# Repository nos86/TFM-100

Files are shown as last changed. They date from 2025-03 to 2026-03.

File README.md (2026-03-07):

# TFM-100 — Thermal Flow Meter

> **TFM-100** is an open-source embedded system for monitoring thermal energy in hydronic circuits. It measures supply and return water temperatures together with volumetric flow rate, calculates instantaneous power and cumulative energy, and publishes all data in real time over a CAN bus (J1939) and a USB serial interface.

---

## Table of Contents

1. [Project Overview](#1-project-overview)
2. [Hardware](#2-hardware)
3. [Firmware](#3-firmware)
4. [Interface Software — Web UI](#4-interface-software--web-ui)
5. [Communication Protocols](#5-communication-protocols)
6. [Repository Structure](#6-repository-structure)
7. [Getting Started](#7-getting-started)
8. [Hardware Design Files](#8-hardware-design-files)

---

## 1. Project Overview

The TFM-100 is designed for installation in heating/cooling systems. It continuously reads two PT100 RTD temperature probes (supply and return lines) and a pulse-output flow sensor. From these three measurements it computes:

| Measurement | Description |
|---|---|
| Supply temperature | Raw and low-pass-filtered temperature of the supply line |
| Return temperature | Raw and low-pass-filtered temperature of the return line |
| Flow rate | Volumetric flow in litres per hour |
| Thermal power | Instantaneous power in Watts (ΔT × flow × specific heat) |
| Energy total | Cumulative energy in Wh, persisted to EEPROM |
| Energy (24 h) | Rolling 24-hour energy counter, persisted to EEPROM |

All measurements are broadcast on a J1939 CAN bus and are also streamed over USB serial for direct PC access. A browser-based Web UI connects via the **WebSerial API** to display live telemetry, diagnostic trouble codes (DTCs), and a scrolling log—no driver installation required.

---

## 2. Hardware

### 2.1 Microcontroller

| Parameter | Value |
|---|---|
| MCU | **ATmega32U4** |
| Clock | 8 MHz external crystal |
| Supply | 5 V system supply and I/O logic (via USB or external 5 V) |
| Brown-out detection | 2.6 V (efuse `0xCB`) |
| Bootloader | Caterina (CDC ACM, `avr109` protocol) |
| Flash | 28 672 bytes usable |

The ATmega32U4 provides native USB (CDC-ACM serial) without an external USB-to-UART bridge, which means it enumerates directly as a serial port on any OS.

> **Firmware note:** The PlatformIO/Arduino firmware is built using the `ARDUINO_AVR_PROMICRO8` (8 MHz Pro Micro) board definition to match the ATmega32U4 clock and bootloader configuration. The TFM-100 PCB operates at **5 V** — all GPIO logic levels are 5 V. It is **not** a 3.3 V Pro Micro, so connect only 5 V–tolerant peripherals or use appropriate level shifting.

### 2.2 Temperature Sensing — PT100 RTDs

Two **PT100** resistance temperature detectors are read by two independent **MAX31865** SPI RTD-to-digital converter ICs. Each MAX31865 performs the resistance-to-temperature conversion on-chip and communicates over SPI.

| Signal | Arduino Pin | MCU Pin |
|---|---|---|
| Supply PT100 CS | D2 (SDA) | PD1 |
| Return PT100 CS | D3 (SCL) | PD0 |
| SPI SCK | SCK | PB1 |
| SPI MOSI | MOSI | PB2 |
| SPI MISO | MISO | PB3 |

A software **low-pass filter** (RC ≈ 5 s, sampled at 100 ms) is applied to each reading to suppress noise before the value is used for energy calculations.

### 2.3 Flow Sensing

A pulse-output flow sensor is connected to the hardware interrupt pin. The firmware counts pulses in an ISR with debouncing and converts ticks to litres per hour using a configurable factor (default: **4 ticks/litre**). A timeout detects sensor removal or zero flow.

| Signal | Arduino Pin | MCU Pin |
|---|---|---|
| Flow pulse | D0 (RX) | PD2 |

### 2.4 CAN Bus — MCP2515

A **MCP2515** SPI-to-CAN controller provides a J1939-compatible CAN 2.0B interface (29-bit extended IDs) at 250 kbit/s.

| Signal | Arduino Pin | MCU Pin |
|---|---|---|
| MCP CS | D4 | PD4 |
| MCP INT | D7 | PE6 |
| SPI (shared with PT100) | SCK / MOSI / MISO | PB1–PB3 |

### 2.5 Node ID Configuration — DIP Switch

Four DIP switch bits select the lower nibble of the J1939 node ID at power-on. The base address is `0x10`, giving a configurable range of `0x10`–`0x1F`.

| Bit | Arduino Pin |
|---|---|
| B0 | D6 |
| B1 | D8 |
| B2 | D9 |
| B3 | D10 |

### 2.6 Status LEDs

| LED | Arduino Pin | Meaning |
|---|---|---|
| Red (RX LED) | `LED_BUILTIN_RX` | Error / fault severity indication (pattern-based: flash counts, blink, solid) |
| Green (TX LED) | `LED_BUILTIN_TX` | Node state indication (pattern-based: RUN / STOP / SLEEP / SETUP / CLI) |

The firmware drives both LEDs with defined patterns rather than fixed on/off states:

| LED | State / Condition | Pattern |
|---|---|---|
| **Green** | CLI client connected | 2.5 Hz blink |
| **Green** | RUN | Solid ON |
| **Green** | SLEEP | Single flash |
| **Green** | SETUP | Inverted flicker (10 Hz) |
| **Green** | STOP | Off |
| **Red** | No fault | Off |
| **Red** | Severity 1 | Single flash |
| **Red** | Severity 2 | Double flash |
| **Red** | Severity 3 | Triple flash |
| **Red** | Severity 4 (critical) | Solid ON |
| **Red** | Severity 5 (warning) | 2.5 Hz blink |
| **Red** | Severity > 5 | 10 Hz flicker |

---

## 3. Firmware

The firmware is written in C++ for the Arduino / PlatformIO ecosystem and targets the ATmega32U4. It is structured as a set of loosely coupled modules that all run cooperatively under a lightweight task scheduler.

### 3.1 Architecture Overview

```
┌─────────────────────────────────────────────────────────────┐
│                        main loop                            │
│  scheduler::run() dispatches tasks at configured intervals  │
└───────────┬──────────┬──────────┬─────────────┬────────────┘
            │          │          │             │
     ┌──────▼──┐  ┌────▼────┐  ┌──▼───────┐  ┌──▼────────┐
     │  PT100  │  │  Flow   │  │ J1939Mgr │  │  Serial   │
     │ sensor  │  │ sensor  │  │  (CAN)   │  │  CLI/Log  │
     └──────┬──┘  └────┬────┘  └──────────┘  └──────────┘
            │          │
     ┌──────▼──────────▼──────┐
     │  power.cpp / energy.cpp│  (calculations + EEPROM persistence)
     └────────────────────────┘
```

### 3.2 Key Modules

| Module | Source | Description |
|---|---|---|
| **Scheduler** | `lib/scheduler/` | Cooperative task scheduler; each task specifies its interval in milliseconds |
| **PT100 driver** | `lib/PT100/` | Non-blocking MAX31865 driver with built-in low-pass filter |
| **Flow sensor** | `lib/flow/` | ISR-driven pulse counter with debounce and zero-flow timeout |
| **J1939 Manager** | `lib/J1939/` | Complete J1939 stack: message registry, single-frame TX, BAM Transport Protocol |
| **J1939 DM1** | `lib/J1939/J1939_DM.cpp` | Diagnostics Module 1 — broadcasts active DTCs on the CAN bus |
| **Serial Protocol** | `lib/SerialProtocol/` | ASCII line-oriented CLI (see §5.2) |
| **Diagnostics** | `lib/diagnostics/` | DTC storage, debouncing, SPN/FMI encoding |
| **Power** | `src/power.cpp` | Computes instantaneous thermal power from ΔT and flow |
| **Energy** | `src/energy.cpp` | Integrates power over time; persists totals to EEPROM once per minute |
| **CAN messages** | `src/can_messages.cpp` | Concrete J1939 message objects (Heartbeat, Temperature, Power/Energy) |
| **CLI** | `src/cli.cpp` | Handles host commands (calibration, memory read/write, reboot) |
| **LEDs** | `src/LEDs.cpp` | Maps system state to LED patterns |
| **DIP switch** | `src/dip_switch.cpp` | Reads node-ID DIP switch at startup |

### 3.3 EEPROM Layout

| Region | Offset | Size | Contents |
|---|---|---|---|
| Power | `0x1A–0x1F` | 6 B | Magic word + max observed power |
| Energy | `0x20–0x29` | 10 B | Magic word + cumulative energy + 24 h energy |
| Diagnostics | `0x40+` | variable | DTC ring buffer |

Compile-time `static_assert` guards prevent accidental region overlaps.

### 3.4 CAN Message Summary

All CAN messages use **little-endian (LSB-first)** byte order for multi-byte fields.

| PGN | Period | Payload |
|---|---|---|
| `0xFF10` Heartbeat | 1 s | MODEL (byte 0), firmware version (byte 1), variant & node state (byte 2: high nibble = variant, low nibble = node state), reserved (byte 3), uptime counter (bytes 4–7, little-endian) |
| `0xFF11` Raw Temperature | 1 s | Supply & return raw temperatures (×100, 0.01 °C/LSB, little-endian) |
| `0xFF12` Filtered Temp + Flow | 1 s | Filtered temperatures (×100, 0.01 °C/LSB, little-endian) + flow rate (L/h) |
| `0xFF13` Power & Energy | 1 s | 24 h energy (bytes 0–1, 0.01 kWh/LSB) + energy total (bytes 2–4, 24-bit, 1 kWh/LSB) + power (bytes 5–6, 0.1 kW/LSB) + reserved (byte 7) |
| `0xFECA` DM1 | configured interval (while DTCs active; one final frame on clear) | Active diagnostic trouble codes (SPN + FMI) |

### 3.5 Build & Flash

Requirements: [PlatformIO](https://platformio.org/) (VS Code extension or CLI).

```bash
# Build firmware
cd firmware
pio run

# Flash over USB (Caterina bootloader — press reset twice to enter bootloader)
pio run --target upload

# Open serial monitor
pio device monitor --baud 115200
```

The custom board definition (`firmware/boards/TFM_100.json`, with variants in `firmware/boards/variants/TFM_100/`) sets `8 MHz`, `5V`, and the correct fuse bytes.

---

## 4. Interface Software — Web UI

The **TFM-100 Web UI** is a single-page application built with **Vue 3** and **Vuetify 3**. It runs entirely in the browser and communicates with the device using the [**WebSerial API**](https://developer.mozilla.org/en-US/docs/Web/API/Web_Serial_API) (no driver, no backend required).

> **Browser support**: Chromium-based browsers (Chrome 89+, Edge 89+). Firefox and Safari do not yet support WebSerial.

### 4.1 Features

| Feature | Description |
|---|---|
| **Live telemetry** | Real-time display of all `P;key;value` parameters (temperatures, flow, power, energy) |
| **Diagnostics panel** | Shows active DTCs with SPN-FMI codes and human-readable descriptions |
| **Log viewer** | Scrolling log output of device messages |
| **Serial connection** | Quick connect/disconnect to a selected serial port via the WebSerial API |
| **Browser-only UI** | Runs entirely in the browser; no drivers or backend services required |

### 4.2 Running the Web UI

Requirements: [Node.js](https://nodejs.org/) 18+.

```bash
cd webui
npm install
npm run dev        # Development server with hot-reload
npm run build      # Production build → dist/
```

### 4.3 UI Architecture

```
webui/src/
├── App.vue                      # Root component, serial lifecycle
├── components/
│   ├── TelemetryCard.vue       # Temperature / flow / power / energy display
│   ├── DiagnosticsCard.vue     # DTC list
│   ├── LogFooter.vue           # Scrolling log
│   └── SerialCard.vue          # Manual command input
└── plugins/webserial/
    ├── service.ts              # WebSerial API wrapper
    ├── composable.ts           # Vue reactive composable
    └── adapter.ts              # Serial protocol framing & parsing
```

---

## 5. Communication Protocols

### 5.1 J1939 CAN Bus

TFM-100 uses the **SAE J1939** protocol over a 250 kbit/s CAN 2.0B network with 29-bit extended identifiers.

The `J1939Manager` library provides:

- **Message registration** — up to 10 message types with configurable TX periods.
- **Single-frame TX** — payloads ≤ 8 bytes sent directly.
- **BAM Transport Protocol** — larger payloads fragmented and reassembled per SAE J1939-21.
- **DM1 diagnostics** — active DTC broadcast whenever fault state changes.

### 5.2 USB Serial (ASCII CLI)

A line-oriented ASCII protocol is used for configuration, diagnostics, and log streaming over USB CDC-ACM. All frames are semicolon-delimited and terminated with `\r\n`.

#### Host → Device (Commands)

| Command | Format | Description |
|---|---|---|
| Erase diagnostics | `E\r\n` | Clears the DTC ring buffer in EEPROM |
| Set calibration | `C;<id>;<value>\r\n` | Write a calibration coefficient |
| Read memory | `R;<chip>;<addr_hex>;<len_dec>\r\n` | Dump raw memory (`len` is a decimal byte count) |
| Write memory | `W;<chip>;<addr_hex>;<data_hex>\r\n` | Write raw bytes |
| Reboot | `B\r\n` | Software reset |

#### Device → Host (Uplink)

| Frame | Format | Description |
|---|---|---|
| Telemetry | `P;<key>;<value>\r\n` | Named parameter (e.g. `P;ST;43.2`) |
| Log | `L;<level>;<message>\r\n` | Level: `E`/`W`/`I`/`D` |
| DTC count | `D;<count>\r\n` | Number of stored DTCs |
| DTC entry | `D;<idx>;<desc>;<SPN>-<FMI>;<status>;<oc>\r\n` | Individual trouble code |
| Memory dump | `V;<chip>;<addr_hex>;<len_hex>;<hex_data>\r\n` | Response to `R` command (`len_hex` is exactly 2 hex digits; `addr_hex` is up to 8 hex digits) |
| Calibration | `C;<id>;<type>;<value>\r\n` | Current calibration value |

A full protocol specification is available in [PROTOCOL.md](PROTOCOL.md).

---

## 6. Repository Structure

```
TFM-100/
├── README.md                    # This file
├── PROTOCOL.md                  # Full serial CLI protocol specification
├── firmware/                    # ATmega32U4 firmware (PlatformIO / C++)
│   ├── src/                     # Application source files
│   ├── include/                 # Project-wide headers and config
│   ├── lib/                     # Reusable libraries
│   │   ├── J1939/               # J1939 CAN stack
│   │   ├── SerialProtocol/      # ASCII serial protocol
│   │   ├── PT100/               # MAX31865 RTD driver
│   │   ├── flow/                # Flow sensor driver
│   │   ├── scheduler/           # Cooperative task scheduler
│   │   └── diagnostics/         # DTC management
│   ├── boards/TFM_100.json      # Custom PlatformIO board definition
│   ├── boards/variants/TFM_100/ # Board-specific pin/variant files
│   └── platformio.ini           # Build configuration
├── webui/                       # Browser-based monitoring UI (Vue 3)
│   ├── src/
│   │   ├── components/          # Vue components
│   │   └── plugins/webserial/   # WebSerial API integration
│   └── package.json
├── hardware/                    # PCB design and manufacturing files
│   ├── schematics.pdf           # Circuit schematic
│   ├── board.png                # PCB layout preview
│   ├── ThermalFlowMeter-BoM.xlsx          # Bill of Materials
│   ├── ThermalFlowMeter_PickAndPlace.xlsx # Pick & place data
│   ├── ThermalFlowMeter-gerber.zip        # Gerber files (ready for fab)
│   └── easyeda_project.epro               # EasyEDA schematic project
└── bootloader/                  # Bootloader flashing guide & hex file
    └── README.md                # avrdude flashing instructions
```

---

## 7. Getting Started

### Prerequisites

| Tool | Purpose |
|---|---|
| [PlatformIO](https://platformio.org/) | Firmware build & upload |
| [Node.js 18+](https://nodejs.org/) | Web UI development |
| USBasp programmer | Initial bootloader programming (if blank chip) |
| Chromium-based browser | Web UI runtime |

### Step 1 — Flash the Bootloader (first time only)

If your ATmega32U4 is blank, follow the instructions in [`bootloader/README.md`](bootloader/README.md) to flash the Caterina USB bootloader using a USBasp programmer.

### Step 2 — Build and Upload Firmware

```bash
cd firmware
pio run --target upload   # Connect USB; double-tap reset to enter bootloader
```

### Step 3 — Run the Web UI

```bash
cd webui
npm install
npm run dev
```

Open `http://localhost:3000` in Chrome or Edge, click **Connect**, and select the TFM-100 serial port.

---

## 8. Hardware Design Files

All hardware design files are located in the [`hardware/`](hardware/) directory.

| File | Description |
|---|---|
| `schematics.pdf` | Full circuit schematic |
| `board.png` | PCB layout preview image |
| `ThermalFlowMeter-BoM.xlsx` | Bill of Materials |
| `ThermalFlowMeter_PickAndPlace.xlsx` | SMT pick & place data |
| `ThermalFlowMeter-gerber.zip` | Gerber + drill files for PCB fabrication |
| `easyeda_project.epro` | Editable EasyEDA schematic project |

---

*For questions, bug reports, or contributions, please open an issue or pull request on this repository.*

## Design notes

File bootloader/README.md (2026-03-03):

# Flashing the Bootloader on ATmega32U4 Using avrdude

This guide explains how to flash the bootloader onto an ATmega32U4 microcontroller
using a USBasp programmer and the `avrdude` command. It covers the necessary pin
connections and explains the meaning of fuse settings.

## Prerequisites

*   **ATmega32U4 microcontroller**: The target chip for the bootloader.
*   **USBasp programmer**: A low-cost USB programmer for Atmel AVR microcontrollers.
*   **avrdude**: The tool used to interface with the ATmega32U4 via the USBasp.
*   **Caterina Bootloader Hex File**: The bootloader file (`Caterina-promicro8.hex`)
    for the ATmega32U4.

## Hardware Setup

### Step 1: Connect the USBasp to the ATmega32U4

The USBasp exposes a standard 10-pin AVR ISP header. The pin numbering (odd pins
on the left column, even pins on the right column, pin 1 indicated by the triangle
or notch on the connector) is:

```
10-pin AVR ISP header (front view)
        ┌───────┬
 MOSI ← │  1  2 │ → VCC
   NC ← │  3  4 │ → GND
  RST ← │  5  6 │ → GND
  SCK ← │  7  8 │ → GND
 MISO ← │  9 10 │ → GND
        └───────┘
```

Connect the relevant signals to the ATmega32U4 as follows:

| 10-pin ISP Pin | Signal | ATmega32U4 Pin |
| --- | --- | --- |
| 1 | MOSI | MOSI |
| 2 | VCC | **CONNECTED ONLY IF 3.3V** |
| 4 / 6 / 8 / 10 | GND | GND |
| 5 | RST | RESET |
| 7 | SCK | SCK |
| 9 | MISO | MISO |

> **Note**: This board uses a 3.3 V power supply. Use VCC from USBasp
> only if it is able to provide 3.3V and **NOT** 5V, otherwise power the
> target board separately via USB.

#### Adapter for 6-pin ICSP Connectors

To simplify the connection with standard 6-pin ICSP header, you can use a 10-to-6 
pin ISP adapter to connect the USBasp directly without individual wires:

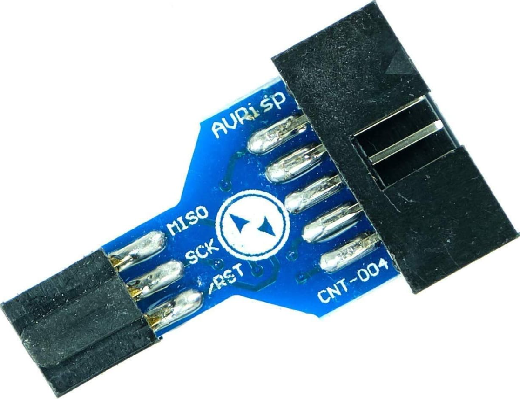
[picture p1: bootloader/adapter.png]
10-to-6 pin ISP adapter


These adapters convert the USBasp 10-pin IDC connector to the 6-pin ICSP layout and
are widely available online.

### Step 2: Verify the Connections

Make sure the connections are correct as outlined in the table above before
proceeding to the next steps.

## Flashing the Bootloader

Once the hardware is set up, flash the bootloader on the ATmega32U4 using `avrdude`.

### Step 3: Program the Fuses

Because the crystal oscillator fuses may be incorrectly configured, the ISP clock
must be reduced to a very low speed (`-B400`) for the initial fuse programming step.

Run the following command from the terminal:

```bash
avrdude -cusbasp -pm32u4 -B400 -U lfuse:w:0xFF:m -U hfuse:w:0xD8:m -U efuse:w:0xCB:m
```

**Explanation of flags:**

*   `-cusbasp`: Selects the USBasp as the programmer.
*   `-pm32u4`: Targets the ATmega32U4 microcontroller.
*   `-B400`: Sets the ISP bit-clock period to 400 µs (very slow) to communicate
    reliably when the crystal is not yet configured correctly.
*   `-U lfuse:w:0xFF:m`: Sets the low fuse to `0xFF` (external crystal, no
    prescaler).
*   `-U hfuse:w:0xD8:m`: Sets the high fuse to `0xD8` (`BOOTRST` programmed so
    the chip resets into the bootloader; `BOOTSZ=00` selects the 4096-byte
    bootloader section).
*   `-U efuse:w:0xCB:m`: Sets the extended fuse to `0xCB` (Brown-Out Detection
    threshold at 2.4 V; Hardware Boot Enable pin disabled).

### Step 4: Flash the Bootloader

After the fuses are correctly set the chip can be programmed at full ISP speed.

Run the following command from the terminal:

```bash
avrdude -cusbasp -pm32u4 -e -U flash:w:Caterina-promicro8.hex
```

**Explanation of flags:**

*   `-cusbasp`: Selects the USBasp as the programmer.
*   `-pm32u4`: Targets the ATmega32U4 microcontroller.
*   `-e`: Erases the flash memory of the ATmega32U4 before programming.
*   `-U flash:w:Caterina-promicro8.hex`: Writes the Caterina bootloader to flash.

### Step 5: Wait for the Process to Complete

`avrdude` will write the bootloader to the ATmega32U4. Wait for the process to
finish. You should see a message indicating successful programming.

## Fuse Explanation

Fuses are special bits stored in the ATmega32U4 that control the hardware
configuration of the microcontroller, such as the clock source, bootloader settings,
and memory protection. This guide uses three fuse bytes:

*   **LFUSE (Low Fuse) = `0xFF`**: Selects the external crystal oscillator as the
    clock source with no clock division (prescaler = 1). The chip runs at the full
    8 MHz frequency of the external crystal.

*   **HFUSE (High Fuse) = `0xD8`** (`0xD8` = `0b11011000`):
    *   `BOOTRST` = 0 (programmed, active-low): the MCU jumps to the bootloader
        section on every reset, enabling USB programming.
    *   `BOOTSZ[1:0]` = `00` (both bits programmed): selects the maximum 2048-word
        (4096-byte) bootloader section.
    *   `SPIEN` = 0 (programmed): SPI programming interface enabled.

*   **EFUSE (Extended Fuse) = `0xCB`** (`0xCB` = `0b11001011`):
    *   `BODLEVEL[2:0]` = `011`: sets the Brown-Out Detection threshold to 2.6 V,
        preventing flash corruption if the supply voltage drops too low.
    *   `HWBE` = 1 (unprogrammed): the Hardware Boot Enable pin (HWB) is disabled;
        the bootloader is always entered on reset (see `BOOTRST` above).

## Troubleshooting

*   **Verification error**: Re-run the `avrdude` command with the `-v` flag for
    verbose output to help diagnose the problem.
*   **USBasp not detected**: Ensure the USBasp is properly connected via USB and
    that its drivers are installed. On Linux you may need to add a udev rule or run
    `avrdude` with `sudo`.

---

This guide provides step-by-step instructions to program an ATmega32U4 with the
**Caterina bootloader** using a USBasp programmer and explains the fuse settings.
Follow the steps carefully to ensure successful bootloader flashing.

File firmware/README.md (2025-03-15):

# ATmega32U4-Arduino Pin Mapping

A diagram showing the correspondence between the pins on an Arduino board and those of the ATmega32U4 microcontroller.

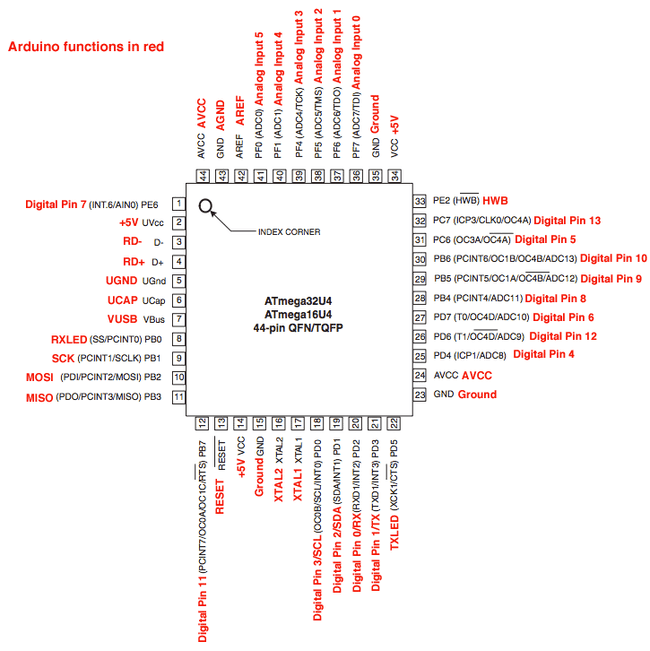
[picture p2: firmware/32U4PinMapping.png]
32U4 Pin Mapping


**Last revision:** 08/02/2024

## ATmega32U4 Pin Mapping

### Arduino Leonardo Pin Mapping Table

| Pin Number | Pin Name | Mapped Pin Name |
|---|---|---|
| 1 | PE6 (INT.6/AIN0) | Digital pin 7 |
| 2 | UVcc | +5V |
| 3 | D- | RD- |
| 4 | D+ | RD+ |
| 5 | UGnd | UGND |
| 6 | UCap | UCAP |
| 7 | VUSB | VBus |
| 8 | (SS/PCINT0) PB0 | RXLED |
| 9 | (PCINT1/SCLK) PB1 | SCK |
| 10 | (PDI/PCINT2/MOSI) PB2 | MOSI |
| 11 | (PDO/PCINT3/MISO) PB3 | MISO |
| 12 | (PCINT7/OC0A/OC1C/#RTS) PB7 | Digital pin 11 (PWM) |
| 13 | RESET | RESET |
| 14 | Vcc | +5V |
| 15 | GND | GND |
| 16 | XTAL2 | XTAL2 |
| 17 | XTAL1 | XTAL1 |
| 18 | (OC0B/SCL/INT0) PD0 | Digital pin 3 (SCL)(PWM)  |
| 19 | (SDA/INT1) PD1 | Digital pin 2 (SDA) |
| 20 | (RX D1/AIN1/INT2) PD2 | Digital pin 0 (RX) |
| 21 | (TXD1/INT3) PD3 | Digital pin 1 (TX) |
| 22 | (XCK1/#CTS) PD5 | TXLED |
| 23 | GND1 | GND |
| 24 | AVCC | AVCC |
| 25 | (ICP1/ADC8) PD4 | Digital pin 4 |
| 26 | (T1/#OC4D/ADC9) PD6 | Digital pin 12 |
| 27 | (T0/OC4D/ADC10) PD7 | Digital Pin 6 (PWM) |
| 28 | (ADC11/PCINT4) PB4 | Digital pin 8 |
| 29 | (PCINT5/OC1A/#OC4B/ADC12) PB5 | Digital Pin 9 (PWM) |
| 30 | (PCINT6/OC1B/OC4B/ADC13) PB6  | Digital Pin 10 (PWM) |
| 31 | (OC3A/#0C4A) PC6 | Digital Pin 5 (PWM) |
| 32 | (ICP3/CLK0/)0C4A) PC7 | Digital Pin 13 (PWM) |
| 33 | (#HWB) PE2 | HWB |
| 34 | Vcc1 | +5V |
| 35 | GND2 | GND |
| 36 | (ADC7/TDI) PF7 | Analog In 0 |
| 37 | (ADC6/TDO) PF6 | Analog In 1 |
| 38 | (ADC5/TMS) PF5 | Analog In 2 |
| 39 | (ADC4/TCK) PF4 | Analog In 3 |
| 40 | (ADC1) PF1 | Analog In 4 |
| 41 | (ADC0) PF0 | Analog In 5 |
| 42 | AREF | AEF |
| 43 | GND3 | GND |
| 44 | AVCC1 | AVCC |

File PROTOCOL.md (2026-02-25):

# TFM-100 Serial / CLI Protocol

## Scope

This document describes the simple, line-oriented serial protocol implemented by the firmware's `SerialProtocol` (see `firmware/lib/SerialProtocol/SerialProtocol.*`). It's used for diagnostics, configuration (calibration), and binary memory read/write operations. The protocol is intentionally minimal and human-readable for easy debugging over serial terminals and bridges.

## Framing

- Messages are ASCII, terminated by LF ("\n") and CR ("\r"), even if, it is optional. Each message is a semicolon-separated list of tokens.
- No binary framing, no escaping. Maximum line size is limited by the firmware buffer (~128 bytes).

## Command directions

- Uplink (host -> device): single-letter commands the firmware parses when a line arrives.
- Downlink (device -> host): responses and notifications emitted by the firmware using the same semicolon-separated format.

## Uplink (host -> device) commands

- `E`
  - Erase diagnostics memory. No parameters.
  - Handler: triggers the erase diagnostics callback (set via `set_erase_diagnostics_callback`).
  - Answer: device will respond with:
    - `E;OK\r\n` on success
    - `E;ERR;error_code\r\n` on failure

- `C;id;value`
  - Calibration command: it is used to change calibration in the firmware.
    - `id` is the identifier of the calibration. Only calibration with identifier can be modified.
    - `value` is an arbitrary string payload interpreted by the firmware.
  - Example: `C;1;5.2\r\n`
  - Handler: triggers the calibration callback (set via `set_calibration_callback`).
  - Answer: device will response as:
    - `C;OK\r\n` to indicate success
    - `C;ERR;error_code\r\n` to indicate failure
- `R;chip_id;addrhex;lenhex`
  - Read address on companion chips:
    - `chip_id` is decimal chip id
    - `addrhex` is an address in hex (big-endian, no 0x)
    - `lenhex` is a decimal length.
  - Example: `R;0;1F2A;16\r\n` (read 16 bytes from address 0x1F2A of chip 0)
  - Handler: triggers the read callback (set via `set_read_callback`).
  - Answer: device will respond with:
    - `V;chip;addrhex;lenhex;datahex\r\n` on success
    - `V;ERR;error_code\r\n` on failure

- `W;chip_id;addrhex;datahex`
  - Write address on companion chips:
    - `chip_id` is decimal chip id
    - `addrhex` is an address in hex (big-endian, no 0x)
    - `datahex` is even-length hex-encoded bytes. Max data length limited by firmware (48 bytes).
  - Example: `W;0;1F2A;0A1B2C3D\r\n` (write bytes 0x0A,0x1B,0x2C,0x3D to address 0x1F2A)
  - Handler: triggers the write callback (set via `set_write_callback`).
  - Answer: device will respond with:
    - `W;OK\r\n` on success
    - `W;ERR;error_code\r\n` on failure

- `B`
  - Reboot. No parameters.
  - Handler: triggers the reboot callback (set via `set_reboot_callback`).
  - Answer: device will respond with `B;OK\r\n` and then reboot.

## Downlink (device -> host) messages

- `P;key;value`
  - Parameter report:
    - `key` is a short ASCII key
    - `value` is a decimal or string. Used for telemetry/parameters.
  - Example: `P;ST;43.2\r\n` (parameter "ST" with value 43.2 - Supply Temperature)

- `L;level;message`
  - Log line:
    - `level` is one of `E` (error), `W` (warning), `I` (info), `D` (debug).
  - Example: `L;I;Initialization complete\r\n`

- `D;count`
  - Diagnostics count: it indicates how many diagnostic trouble codes (DTCs) are currently stored in the device.

- `D;index;Description;SPN-FMI;status;OC`
  - Diagnostics entry. Each line provides details about a specific DTC:
    - `index`: zero-based index of the DTC.
    - `Description`: human-readable description of the DTC.
    - `SPN-FMI`: SPN and FMI code in hex format `SPN-FMI` (e.g., `12F4-A`).
    - `status`: indicates the status of DTC (`PENDING`, `ACTIVE`, `HEALING`, `HISTORY`)
    - `OC`: occurrence count (decimal).
  - Example: `D;3\r\n` then several `D;...` lines.

- `V;chip;addrhex;lenhex;datahex`
  - Hex dump of `lenhex` bytes at `addrhex` for `chip`. `lenhex` is exactly two hex digits; `datahex` is twice that many hex chars.
  - It is the response to a read command.
  - Example: `V;0;1F2A;04;0A1B2C3D\r\n`

- `C;id;type;value`
  - Calibration status from device:
    - `id` is the calibration identifier
    - `type` is one of `I`,`F`,`S` (int, float, string)
    - `value` is the current calibration value
  - Example: `C;1;I;0\r\n`

## Error handling and limits

- The parser silently ignores malformed or unknown commands.
- Maximum inbound line length: ~128 bytes. Overflow resets the inbound buffer.
- Max binary write length: 48 bytes (enforced by `DATA_MAX_BYTES`).

## Implementation notes for integrators

- The firmware `DiagComm` wrapper calls `comm.begin()` to install a Serial writer and exposes higher-level helpers (send_param, send_log, send_diag_info, send_v_dump).
- When adding new downlink message types or changing existing formats, update both the firmware serializer and any web UI parsers that consume these lines.
- The wire format is intentionally human-readable. For automation, prefer using the explicit hex fields (for binary blobs) and PGN/field formats for CAN messages.

Examples

- Host requests 16 bytes starting at 0x100 on chip 0:

```text
R;0;0100;16
```

- Device responds with a dump (example):

```text
V;0;0100;10;11223344556677889900AABBCCDDEEFF
```

- Host sets calibration id 2 to value 1.5:

```text
C;2;F;1.5
```

- Device logs an info:

```text
L;I;Flow started
```

Where to find code

- Parser and emitter: `firmware/lib/SerialProtocol/SerialProtocol.h` and `.cpp`.
- Integration wrapper and usage: `firmware/include/diag_comm.h` and `firmware/src/main.cpp`.

License and authorship

- See repository root `README.md` for project authorship. This protocol document is a derivative description of the in-repo implementation.

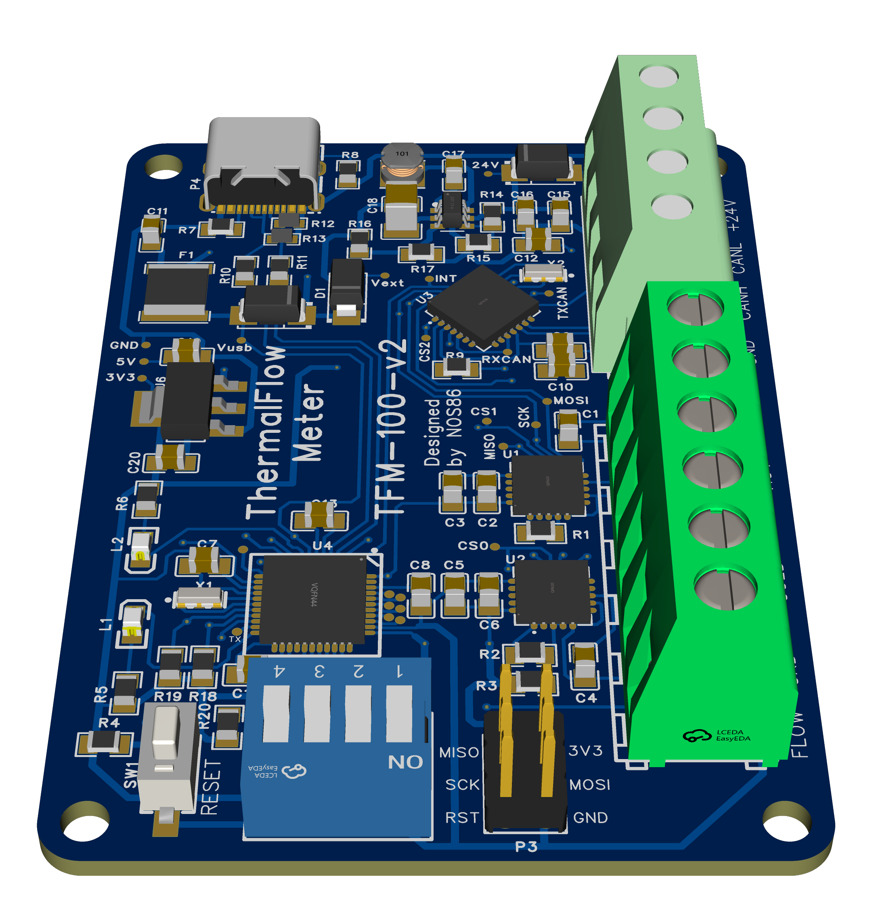
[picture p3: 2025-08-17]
hardware/board.png

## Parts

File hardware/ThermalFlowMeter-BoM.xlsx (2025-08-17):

No. | Quantity | Comment | Designator | Footprint | Value | Manufacturer Part | Manufacturer | Supplier Part | Supplier | JLCPCB Price | Name
1 | 13 | 100nF | C1,C2,C3,C4,C5,C6,C7,C8,C9,C10,C12,C16,C17 | C0805 | 100nF | 0805B104K500NT | FH(风华) | C38141 | LCSC | 0.0006 | 100nF
2 | 2 | 10uF | C11,C19 | C0805 | 10uF | CL21A106KOQNNNE | SAMSUNG(三星) | C1713 | LCSC | 0.0013 | 10uF
3 | 2 | 1uF | C13,C14 | C0805 | 1uF | 0805B105K500NT | FH(风华) | C215803 | LCSC | 0.0014 | 1uF
4 | 1 | 4.7uF | C15 | C0805 | 4.7uF | CL21A475KAQNNNE | SAMSUNG(三星) | C1779 | LCSC | 0.0018 | 4.7uF
5 | 1 | 15uF | C18 | C1210 | 15uF | C3225X7R1C156MT000N | TDK | C694469 | LCSC | 0.0505 | 15uF
6 | 1 | 22uF | C20 | C0805 | 22uF | CL21A226MQQNNNE | SAMSUNG(三星) | C5674 | LCSC | 0.0016 | 22uF
7 | 3 | SS14 | D1,D2,D3 | SMA_L4.3-W2.6-LS5.1-RD |  | SS14 | GOODWORK(固得沃克) | C2986110 | LCSC | 0.0018 | SS14
8 | 1 | MF-SMDF050-2 | F1 | F2018 |  | MF-SMDF050-2 | BOURNS | C210839 | LCSC | 0.0191 | MF-SMDF050-2
9 | 1 | 100uH | H1 | IND-SMD_L3.5-W3.0_SLF0302 | 100uH | CD32YP0302-101M | YJYCOIN(益嘉源) | C492265 | LCSC | 0.0054 | 100uH
10 | 2 | XL-2012SURC | L1,L2 | LED0805-RD_RED |  | XL-2012SURC | XINGLIGHT(成兴光) | C965812 | LCSC | 0.0008 | XL-2012SURC
11 | 1 | MX128-5.0-06P-GN01-Cu-Y-A | P1 | CONN-TH_6P-P5.00_MX128-5.0-06P-GN01-CU-Y-A |  | MX128-5.0-06P-GN01-Cu-Y-A | MAX(迈旭) | C5290371 | LCSC | 0.0502 | MX128-5.0-06P-GN01-Cu-Y-A
12 | 1 | MX128-5.0-04P-GN01-Cu-Y-A | P2 | CONN-TH_4P-MX128-5.0-04P-GN01-CU-Y-A |  | MX128-5.0-04P-GN01-Cu-Y-A | MAX(迈旭) | C5290369 | LCSC | 0.0355 | MX128-5.0-04P-GN01-Cu-Y-A
13 | 1 | 2.54-2*3P针 | P3 | HDR-TH_6P-P2.54-V-M-R2-C3-S2.54-1 |  | 2.54-2*3P针 | BOOMELE(博穆精密) | C65114 | LCSC | 0.0043 | 2.54-2*3P针
14 | 1 | U262-161N-4BVC11 | P4 | USB-3.1-SMD_U262-161N-4BVC11 |  | U262-161N-4BVC11 | XKB Connectivity(中国星坤) | C319148 | LCSC | 0.0309 | U262-161N-4BVC11
15 | 2 | 400Ω | R1,R2 | R0805 | 400Ω | TR0805B400RP0525Z | EVER OHMS(天二科技) | C153298 | LCSC | 0.0043 | 400Ω
16 | 6 | 10kΩ | R3,R4,R9,R18,R19,R20 | R0805 | 10kΩ | 0805W8F1002T5E | UNI-ROYAL(厚声) | C17414 | LCSC | 0.0003 | 10kΩ
17 | 2 | 1kΩ | R5,R6 | R0805 | 1kΩ | 0805W8F1001T5E | UNI-ROYAL(厚声) | C17513 | LCSC | 0.0003 | 1kΩ
18 | 2 | 5.1kΩ | R7,R8 | R0805 | 5.1kΩ | RMC08055.1K5%N | Tyohm(幸亚电阻) | C269736 | LCSC | 0.0006 | 5.1kΩ
19 | 2 | 22Ω | R10,R11 | R0805 | 22Ω | 0805W8F220JT5E | UNI-ROYAL(厚声) | C17561 | LCSC | 0.0003 | 22Ω
20 | 2 | CG0603MLC-05E | R12,R13 | R0603 |  | CG0603MLC-05E | BOURNS | C840634 | LCSC | 0.0278 | CG0603MLC-05E
21 | 1 | 953kΩ | R14 | R0805 | 953kΩ | CR0805F89533G | LIZ(丽智电子) | C101915 | LCSC | 0.0004 | 953kΩ
22 | 1 | 332kΩ | R15 | R0805 | 332kΩ | AC0805FR-07332KL | YAGEO(国巨) | C228750 | LCSC | 0.0006 | 332kΩ
23 | 1 | 95.3kΩ | R16 | R0805 | 95.3kΩ | 0805W8F9532T5E | UNI-ROYAL(厚声) | C17873 | LCSC | 0.0003 | 95.3kΩ
24 | 1 | 22.1kΩ | R17 | R0805 | 22.1kΩ | CR0805-FX-2212ELF | BOURNS | C204311 | LCSC | 0.0016 | 22.1kΩ
25 | 1 | TS-1101-C-W | SW1 | SW-SMD_L6.0-W3.3-LS8.0 |  | TS-1101-C-W | XKB Connectivity(中国星坤) | C318938 | LCSC | 0.0057 | TS-1101-C-W
26 | 1 | SMQS-04R-TP | SW2 | SW-TH_8P-P2.54_SMQS-04R-TP |  | SMQS-04R-TP | SM Switch | C5299505 | LCSC | 0.0341 | SMQS-04R-TP
27 | 2 | MAX31865ATP+T | U1,U2 | QFN-20_L5.0-W5.0-P0.65-BL-EP |  | MAX31865ATP+T | ADI(亚德诺)/MAXIM(美信) | C118474 | LCSC | 0.4788 | MAX31865ATP+T
28 | 1 | MCP25625-E/ML | U3 | QFN-28_L6.0-W6.0-P0.65-BL-EP |  | MCP25625-E/ML | MICROCHIP(美国微芯) | C481365 | LCSC | 0.2769 | MCP25625-E/ML
29 | 1 | ATMEGA32U4-MU | U4 | VQFN-44_L7.0-W7.0-P0.50-BL-EP5.2 |  | ATMEGA32U4-MU | MICROCHIP(美国微芯) | C112161 | LCSC | 0.7507 | ATMEGA32U4-MU
30 | 1 | TPS560430XDBVR | U5 | SOT-23-6_L2.9-W1.6-P0.95-LS2.8-BL |  | TPS560430XDBVR | TI(德州仪器) | C524782 | LCSC | 0.072 | TPS560430XDBVR
31 | 1 | AMS1117-3.3V | U6 | SOT-223-4_L6.5-W3.5-P2.30-LS7.0-TR |  | AMS1117-3.3V | MSKSEMI(美森科) | C5120765 | LCSC | 0.005 | AMS1117-3.3V
32 | 2 | 8MHz | X1,X2 | OSC-SMD_3P-L3.2-W1.3-P1.20-L | 8MHz | CSTNE8M00GH5C000R0 | muRata(村田) | C341525 | LCSC | 0.0323 | 8MHz

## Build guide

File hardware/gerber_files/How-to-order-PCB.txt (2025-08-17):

How to Order PCB

Please refer to:
https://prodocs.easyeda.com/en/pcb/order-order-pcb/index.html

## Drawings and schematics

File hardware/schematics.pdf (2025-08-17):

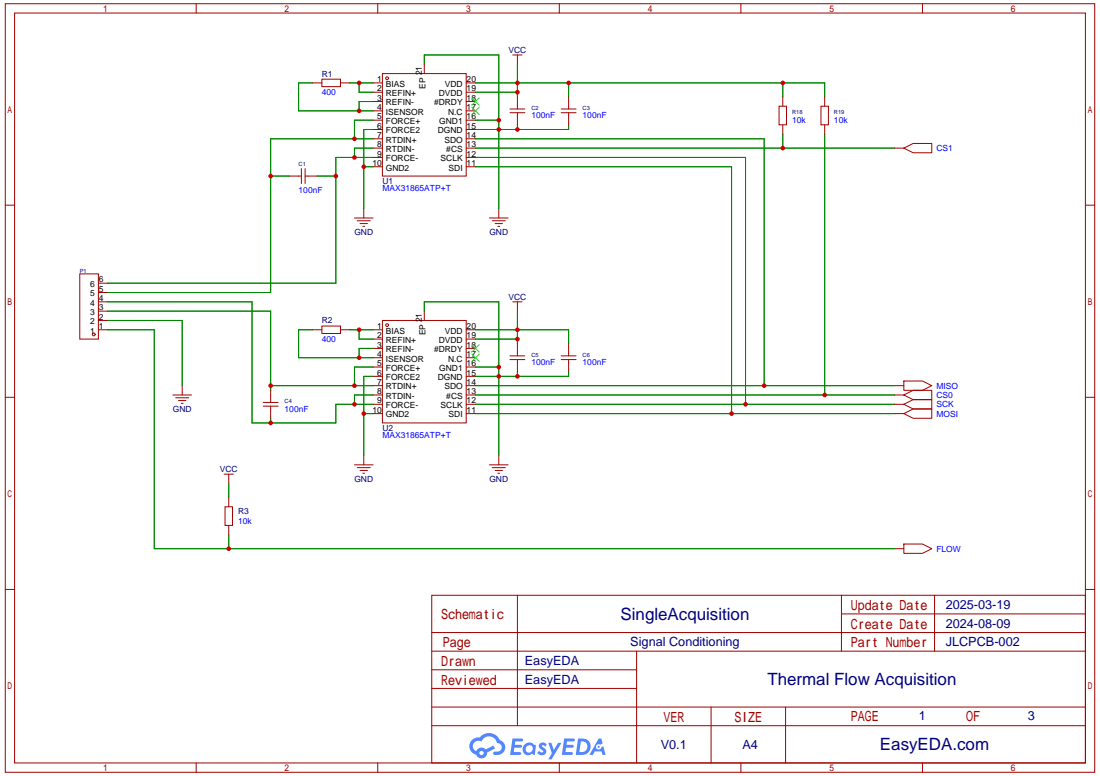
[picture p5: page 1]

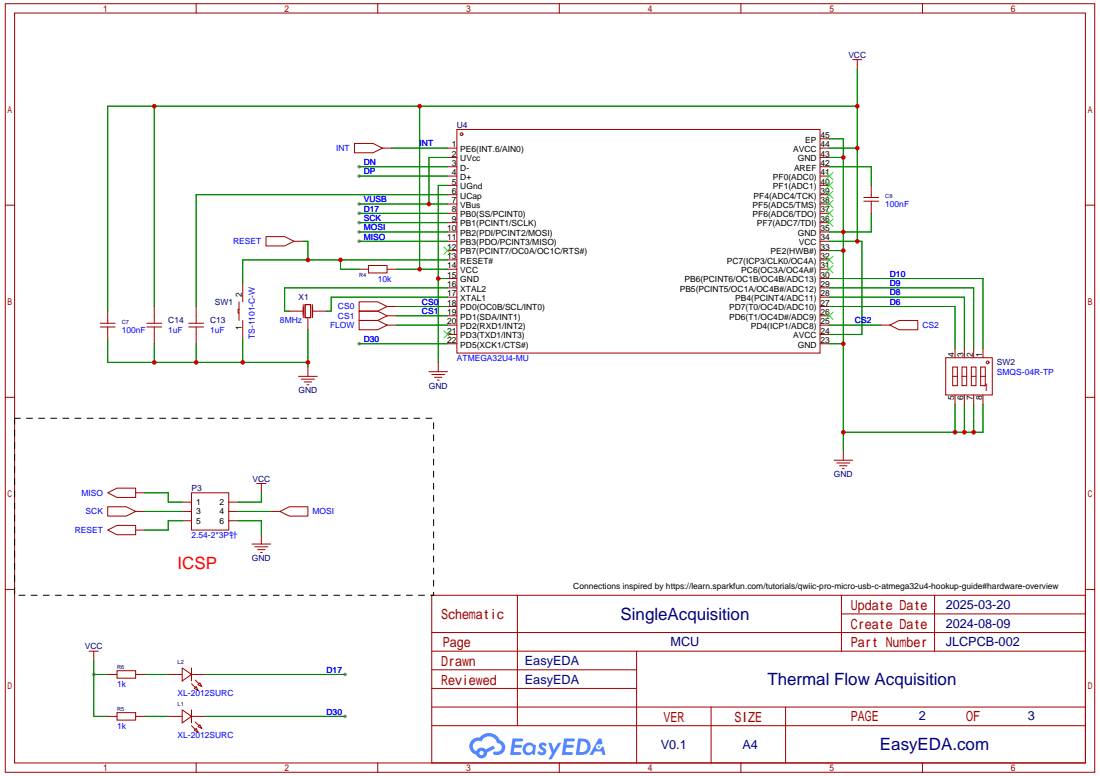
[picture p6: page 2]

Connections inspired by https://learn.sparkfun.com/tutorials/qwiic-pro-micro-usb-c-atmega32u4-hookup-guide#hardware-overview
2024-08-09 SingleAcquisition
MCU

USB Connector | CAN Bus

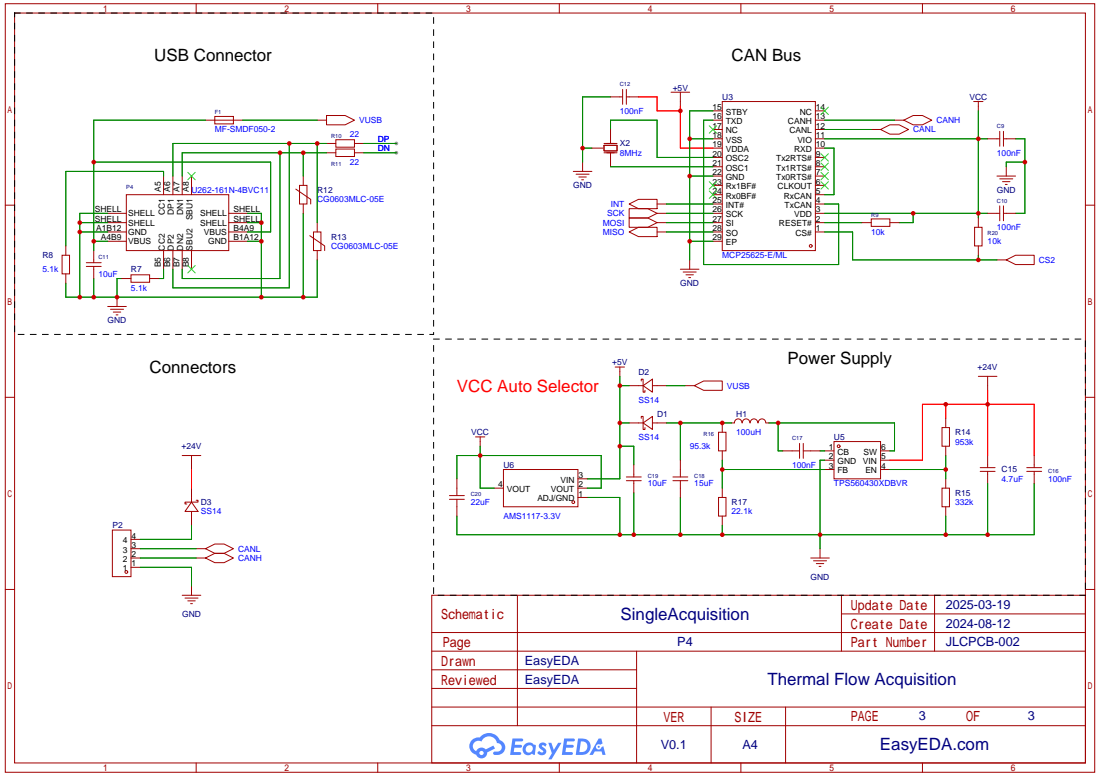
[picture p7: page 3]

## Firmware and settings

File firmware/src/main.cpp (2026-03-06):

/**
 * @file main.cpp
 * @brief Entry point for the TFM-100 firmware: initialize hardware, schedule tasks and run main loop.
 * @author Salvo Musumeci
 * @date 2025-03-09
 *
 * This module configures peripherals (SPI, CAN, sensors), creates the J1939 manager,
 * registers periodic tasks with the cooperative scheduler, and implements the main
 * non-blocking loop that drives sensor state machines and the transport layer.
 */

// The setup function runs once at reset or power-up

// Framework lib
#include <Arduino.h>
#include <SPI.h>
#include "config.h"
#include <avr/wdt.h>
#include <MAX31865_NonBlocking.h>

// MyLib
#include <scheduler.h>
#include <LEDs.h>
#include <PT100.h>
#include <flow.h>
#include <J1939Manager.h>
#include <J1939_DM.h>
#include <diagnostics.h>

// 3rd parties lib
#include <mcp_can.h>

// Include Headers
#include <status.h>
#include <can_messages.h>
#include <McpCanAdapter.h>
#include <dip_switch.h>
#include <dtc.h>
#include <utils.h>
#include <energy.h>
#include <power.h>
#include <diag_comm.h>

/* CLI */

/* Temperature Sensors Variables */
PT100 supply_sensor = PT100(SUPPLY_CS);
PT100 return_sensor = PT100(RETURN_CS);

/* Flow Sensor Variables */
Flow flowObj = Flow(FLOW_TICKS_PER_LITER);
Energy energyObj = Energy();
Power powerObj = Power();

/* Set-up J1939 Transport Layer */
// Allocation of CAN controller and adapter
MCP_CAN CAN0(MCP_CS);           // Set CS to pin 4
McpCanAdapter canAdapter(CAN0); // Adapter per MCP_CAN

// Pass the callbacks struct as the second argument
J1939Callbacks j1939_cbs;

// J1939 Manager instance (created in setup once CAN is initialized)
J1939Manager *j1939 = nullptr; // allocated in setup

/* Node Status */
NodeStatus_t node_status = SETUP;

/* LED Indicators */
LEDs ledIndicators = LEDs(LED_RED, LED_GREEN);

// Scheduler
Scheduler scheduler = Scheduler();

DiagComm diagComm = DiagComm();

/* Node ID */
uint8_t node_id;
uint8_t severity = 0;

bool CANbusOff = false;
bool CANbusWarn = false;
bool HwFailure = true; // Assume HW failure until all init done

// CAN RX interrupt flag
volatile bool canRxPending = false;

/**
 * @brief Interrupt Service Routine for MCP2515 RX interrupt
 * @remarks Called when MCP2515 receives a message. Sets flag for main loop processing.
 */
void canRxInterruptHandler()
{
  canRxPending = true;
}

// serial writer provided below as a free function


/* CAN Messages */
HeartbeatMessage HBMessage = HeartbeatMessage(5000); // 5s interval
CAN_Temperature TempMessage = CAN_Temperature();
CAN_FilteredTemperatureAndFlow TempAndFlowMessage = CAN_FilteredTemperatureAndFlow();
CAN_PowerAndEnergy PowerAndEnergyMessage = CAN_PowerAndEnergy();
J1939_DM1Message DM1 = J1939_DM1Message(1000); // 1s interval

/* Diagnostics */
TFM100_DTC_Dict dtc_dict_instance = TFM100_DTC_Dict();
Diagnostics DSM = Diagnostics(&dtc_dict_instance);

// Forward declaration of J1939Descriptor is available via J1939Manager.h
// Provide a simple error callback to forward J1939 manager errors to CLI
static void j1939_on_error(const J1939Descriptor &desc)
{
  char buf[80];
  // Format PGN in hex with leading 0x using minimal formatter then append message
  mini_hex6(buf, (unsigned long)desc.pgn); // produces 0xNNNNNN\0
  // Append message text after the hex
  char *p = buf + 8;
  const char *msg = " J1939 TX ERROR";
  while (*msg)
    *p++ = *msg++;
  *p = '\0';
  diagComm.send_error(buf);
}

void update_errors();

/**
 * @brief Process received CAN messages
 * @remarks Handles energy reset commands via J1939 Proprietary A message (PGN 0xF183, SA 0x00).
 * Interrupt-driven: only called when canRxPending flag is set by MCP2515 RX interrupt.
 *
 * J1939 Proprietary A Message format:
 * - Priority: 6 (medium)
 * - PGN: 0xF183 (Proprietary A range)
 * - Source Address (SA): 0x00
 * - Combined CAN ID: 0x18F18300
 * - Payload (1-based byte numbering):
 *   - Byte 1: Target node address (0xFF = all nodes, or specific node ID)
 *   - Byte 2: Reset command type
 *     - 0x01: Reset 24h energy counter only
 *     - 0xFF: Reset both 24h and total energy counters
 *   - Bytes 3-8: Reserved
 */
void processReceivedCanMessages()
{
  INT8U len = 0;
  INT8U buf[8] = {0};
  INT32U canId = 0;
  INT8U ext = 0;

  // Clear the interrupt flag before draining the RX buffer so any interrupt
  // arriving during processing sets the flag again and is handled next loop.
  canRxPending = false;

  // Process all available CAN messages
  while (CAN0.checkReceive() == CAN_MSGAVAIL)
  {
    // Read the message
    CAN0.readMsgBuf(&canId, &ext, &len, buf);

    // Check for energy reset command (J1939 Proprietary A PGN 0xF183, SA 0x00, Priority 6)
    // Only process extended frames
    if (ext == 1 && canId == 0x18F18300)
    {
      INT8U target_node = buf[0]; // Byte 1 (1-based)
      INT8U command = buf[1];     // Byte 2 (1-based)

      // Check if message is for this node (0xFF = broadcast to all nodes)
      if (target_node == 0xFF || target_node == node_id)
      {
        // 0x01: Reset 24h energy counter only
        if (command == 0x01)
        {
          energyObj.reset24h();
          diagComm.send_info("Energy 24h reset");
        }
        // 0xFF: Reset both 24h and total energy counters
        else if (command == 0xFF)
        {
          energyObj.resetAll();
          diagComm.send_info("Energy 24h and total reset");
        }
      }
    }
  }
}

void setup()
{
  /**
   * @brief Initialize subsystems and schedule periodic tasks.
   *
   * This routine initializes CLI, serial, CAN controller, sensors and the
   * J1939 transport manager. It registers periodic tasks with the cooperative
   * scheduler and transitions the node into RUN state if initialization
   * succeeds. On failure it displays an error UI for up to 60s then triggers
   * a watchdog reset.
   */

  bool mcp_init = false, mcp_normal = false, supply_init = false, return_init = false;

  /* Configure microcontroller/peripherals. */

  // Serial for CLI/diagnostics output
  diagComm.begin(115200);

  // If diagnostics EEPROM load failed during Diagnostics construction, flag the DTC
  DSM.setRaw(DTC_DSMEepromFailure, !DSM.eepromLoadOk());
  DSM.setRaw(DTC_PowerEepromFailure, !powerObj.eepromLoadOk());
  DSM.setRaw(DTC_EnergyEepromFailure, !energyObj.eepromLoadOk());

  // Compute node address from DIP switches (base + switch value)
  node_id = dip_switch_read() | NODE_ID_BASE;

  // Initialize MCP2515 CAN controller (MCP_ANY - auto filter, 250kbps, external oscillator 8MHz)
  if ((mcp_init = (CAN0.begin(MCP_ANY, CAN_250KBPS, MCP_8MHZ) == CAN_OK)))
    if ((mcp_normal = (CAN0.setMode(MCP_NORMAL) == MCP2515_OK)))
    {
      // Configure CAN filters to accept only J1939 Proprietary A energy reset command
      // Message: PGN 0xF183, SA 0x00, Priority 6 → CAN ID 0x18F18300
      // RXB0: Mask 0 matches all 29 bits, Filter 0 accepts only this message
      CAN0.init_Mask(0, 1, 0x1FFFFFFF);
      CAN0.init_Filt(0, 1, 0x18F18300);

      // RXB1: Mask 1 matches all bits but filters reject all messages (disable RXB1)
      CAN0.init_Mask(1, 1, 0x1FFFFFFF);
      CAN0.init_Filt(2, 1, 0x000); // Impossible to match

      // Configure INT pin as input with pull-up and attach interrupt handler
      // MCP2515 will pull INT low when a message is received
      pinMode(MCP_INT, INPUT_PULLUP);
      attachInterrupt(digitalPinToInterrupt(MCP_INT), canRxInterruptHandler, FALLING);

      // Monitor CAN controller error flags frequently (100ms)
      scheduler.addTask([](uint32_t td)
                        {
                            uint8_t error_flags = CAN0.getError();
                            // Bus-Off when TXBO bit (transmit bus-off) is set
                            CANbusOff = (error_flags & MCP_EFLG_TXBO) != 0;
                            // Warning when any of EWARN, RXWAR, TXWAR bits set (error counters >= 96)
                            CANbusWarn = (error_flags & (MCP_EFLG_EWARN | MCP_EFLG_RXWAR | MCP_EFLG_TXWAR)) != 0; },
                        100);
    }

  // Initialize MAX31865 PT100 sensors (non-blocking drivers)
  supply_init = supply_sensor.begin((float)PT100_ALPHA);
  return_init = return_sensor.begin((float)PT100_ALPHA);

  // If any critical subsystem is not initialized, show hardware failure UI and reboot
  if (!mcp_normal || !supply_init || !return_init)
  {
    DSM.setRaw(DTC_SupplyLineDeviceError, supply_init == false);
    DSM.setRaw(DTC_ReturnLineDeviceError, return_init == false);
    DSM.setRaw(DTC_CANBusDeviceError, mcp_normal == false);

    node_status = STOP;
    bool reboot_now = false;
    while (millis() < 60000 && !reboot_now)
    {
      // drawHardwareFailure returns true when user requests immediate reboot
      // Keep LED state machine ticking and allow scheduled tasks to run
      severity = DSM.getMaxSeverity();
      ledIndicators.process();
      scheduler.run();
    }
    // Force reboot via watchdog if recovery is not requested
    wdt_enable(WDTO_15MS);
    while (1)
      ;
  }

  // Create and initialize J1939 manager with CAN adapter and callbacks
  // Hook error callback to forward J1939 manager errors to CLI
  j1939_cbs.on_error = j1939_on_error;
  j1939 = new J1939Manager(canAdapter, j1939_cbs);
  j1939->begin(node_id);

  // Initialize flow sensor (callback integrates energy on each flow tick)
  flowObj.begin([](float flow)
                {
                // Increase energy counters based on last measured temperatures
                energyObj.increase_energy(supply_sensor.last_temperature,
                                          return_sensor.last_temperature,
                                          1.0f / FLOW_TICKS_PER_LITER);
                powerObj.updatePower(supply_sensor.last_temperature,
                                      return_sensor.last_temperature,
                                      flow); });

  // Add message objects to J1939 manager
  j1939->registerMessage(&HBMessage);
  j1939->registerMessage(&TempMessage);
  j1939->registerMessage(&TempAndFlowMessage);
  j1939->registerMessage(&PowerAndEnergyMessage);
  j1939->registerMessage(&DM1);

  // Schedule periodic PT100 measurements (driver triggers non-blocking measurement)
  scheduler.addTask([](uint32_t td)
                    {
                      if (!supply_sensor.triggerMeasurement())
                        diagComm.send_error("Unable to read SUPPLY");
                      if (!return_sensor.triggerMeasurement())
                        diagComm.send_error("Unable to read RETURN"); },
                    PT100_SAMPLE_RATE);

  // Periodic datastream

  // Periodic diagnostics update (check sensor errors, update DTC memory)
  scheduler.addTask([](uint32_t td)
                    { update_errors(); },
                    1000);

  // All initialization succeeded, enter RUN state
  node_status = RUN;
}

void update_errors()
{
  // Supply Sensor Errors
  DSM.setRaw(DTC_SupplyLineRefInHigh, supply_sensor.last_fault & MAX31865::FAULT_HIGHTHRESH_BIT);
  DSM.setRaw(DTC_SupplyLineRefInLow, supply_sensor.last_fault & MAX31865::FAULT_LOWTHRESH_BIT);
  DSM.setRaw(DTC_SupplyLineRtdInLow, supply_sensor.last_fault & MAX31865::FAULT_RTDINLOW_BIT);
  DSM.setRaw(DTC_SupplyLineUOV, supply_sensor.last_fault & MAX31865::FAULT_OVUV_BIT);

  // Return Sensor Errors
  DSM.setRaw(DTC_ReturnLineRefInHigh, return_sensor.last_fault & MAX31865::FAULT_HIGHTHRESH_BIT);
  DSM.setRaw(DTC_ReturnLineRefInLow, return_sensor.last_fault & MAX31865::FAULT_LOWTHRESH_BIT);
  DSM.setRaw(DTC_ReturnLineRtdInLow, return_sensor.last_fault & MAX31865::FAULT_RTDINLOW_BIT);
  DSM.setRaw(DTC_ReturnLineUOV, return_sensor.last_fault & MAX31865::FAULT_OVUV_BIT);

  // CAN Bus Errors
  DSM.setRaw(DTC_CANBusOff, CANbusOff);
  DSM.setRaw(DTC_CANBusErrorPassive, CANbusWarn);

  DSM.periodic_update();
  severity = DSM.getMaxSeverity();
}

void loop()
{
  /**
   * @brief Main non-blocking loop
   *
   * The scheduler executes registered tasks. The J1939 manager is polled with
   * the current time (ms) so it can manage timed transmissions and timeouts.
   * Sensor state machines and the CLI are progressed here as well. Node power
   * state is updated based on whether flow is present.
   */

  // Run scheduled periodic tasks
  scheduler.run();

  // Let J1939 manager process pending transmissions/timeouts
  if (j1939)
    j1939->process(millis());

  // Process received CAN messages only if interrupt flag is set (e.g., energy reset commands)
  if (canRxPending)
    processReceivedCanMessages();

  // Advance non-blocking sensor state machines
  supply_sensor.process();
  return_sensor.process();
  flowObj.process();

  // Persist energy counters to EEPROM at most once per minute (rate-limited to reduce EEPROM wear)
  energyObj.persistIfDue(millis());

  diagComm.process(millis());

  // Set node mode depending on flow present
  node_status = flowObj.isFlowing() ? RUN : SLEEP;

  // Update LED state machine
  ledIndicators.process();
}

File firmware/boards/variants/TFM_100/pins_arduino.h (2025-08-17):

/*
  pins_arduino.h - Pin definition functions for Arduino
  Part of Arduino - http://www.arduino.cc/

  Copyright (c) 2007 David A. Mellis

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
  $Id: wiring.h 249 2007-02-03 16:52:51Z mellis $
*/

#ifndef Pins_Arduino_h
#define Pins_Arduino_h

#include <avr/pgmspace.h>

// Workaround for wrong definitions in "iom32u4.h".
// This should be fixed in the AVR toolchain.
#undef UHCON
#undef UHINT
#undef UHIEN
#undef UHADDR
#undef UHFNUM
#undef UHFNUML
#undef UHFNUMH
#undef UHFLEN
#undef UPINRQX
#undef UPINTX
#undef UPNUM
#undef UPRST
#undef UPCONX
#undef UPCFG0X
#undef UPCFG1X
#undef UPSTAX
#undef UPCFG2X
#undef UPIENX
#undef UPDATX
#undef TCCR2A
#undef WGM20
#undef WGM21
#undef COM2B0
#undef COM2B1
#undef COM2A0
#undef COM2A1
#undef TCCR2B
#undef CS20
#undef CS21
#undef CS22
#undef WGM22
#undef FOC2B
#undef FOC2A
#undef TCNT2
#undef TCNT2_0
#undef TCNT2_1
#undef TCNT2_2
#undef TCNT2_3
#undef TCNT2_4
#undef TCNT2_5
#undef TCNT2_6
#undef TCNT2_7
#undef OCR2A
#undef OCR2_0
#undef OCR2_1
#undef OCR2_2
#undef OCR2_3
#undef OCR2_4
#undef OCR2_5
#undef OCR2_6
#undef OCR2_7
#undef OCR2B
#undef OCR2_0
#undef OCR2_1
#undef OCR2_2
#undef OCR2_3
#undef OCR2_4
#undef OCR2_5
#undef OCR2_6
#undef OCR2_7

#define NUM_DIGITAL_PINS  31
#define NUM_ANALOG_INPUTS 12

#define TX_RX_LED_INIT  (void)0
#define TXLED0          (void)0
#define TXLED1          (void)0
#define RXLED0          (void)0
#define RXLED1          (void)0

static const uint8_t SDA = 2;
static const uint8_t SCL = 3;
#define LED_BUILTIN 13
#define LED_BUILTIN_RX 17					
#define LED_BUILTIN_TX 30

// Map SPI port to 'new' pins D14..D17
static const uint8_t SS   = 17;
static const uint8_t MOSI = 16;
static const uint8_t MISO = 14;
static const uint8_t SCK  = 15;

// Mapping of analog pins as digital I/O
// A6-A11 share with digital pins
static const uint8_t A0 = 18;
static const uint8_t A1 = 19;
static const uint8_t A2 = 20;
static const uint8_t A3 = 21;
static const uint8_t A4 = 22;
static const uint8_t A5 = 23;
static const uint8_t A6 = 24;   // D4
static const uint8_t A7 = 25;   // D6
static const uint8_t A8 = 26;   // D8
static const uint8_t A9 = 27;   // D9
static const uint8_t A10 = 28;  // D10
static const uint8_t A11 = 29;  // D12

#define digitalPinToPCICR(p)    ((((p) >= 8 && (p) <= 11) || ((p) >= 14 && (p) <= 17) || ((p) >= A8 && (p) <= A10)) ? (&PCICR) : ((uint8_t *)0))
#define digitalPinToPCICRbit(p) 0
#define digitalPinToPCMSK(p)    ((((p) >= 8 && (p) <= 11) || ((p) >= 14 && (p) <= 17) || ((p) >= A8 && (p) <= A10)) ? (&PCMSK0) : ((uint8_t *)0))
#define digitalPinToPCMSKbit(p) ( ((p) >= 8 && (p) <= 11) ? (p) - 4 : ((p) == 14 ? 3 : ((p) == 15 ? 1 : ((p) == 16 ? 2 : ((p) == 17 ? 0 : (p - A8 + 4))))))

//  __AVR_ATmega32U4__ has an unusual mapping of pins to channels
extern const uint8_t PROGMEM analog_pin_to_channel_PGM[];
#define analogPinToChannel(P)  ( pgm_read_byte( analog_pin_to_channel_PGM + (P) ) )

#define digitalPinToInterrupt(p) ((p) == 0 ? 2 : ((p) == 1 ? 3 : ((p) == 2 ? 1 : ((p) == 3 ? 0 : ((p) == 7 ? 4 : NOT_AN_INTERRUPT)))))

#ifdef ARDUINO_MAIN

// On the Arduino board, digital pins are also used
// for the analog output (software PWM).  Analog input
// pins are a separate set.

// ATMEL ATMEGA32U4 / ARDUINO LEONARDO
//
// D0               PD2                 RXD1/INT2
// D1               PD3                 TXD1/INT3
// D2               PD1     SDA         SDA/INT1
// D3#              PD0     PWM8/SCL    OC0B/SCL/INT0
// D4       A6      PD4                 ADC8
// D5#              PC6     ???         OC3A/#OC4A
// D6#      A7      PD7     FastPWM     #OC4D/ADC10
// D7               PE6                 INT6/AIN0
//
// D8       A8      PB4                 ADC11/PCINT4
// D9#      A9      PB5     PWM16       OC1A/#OC4B/ADC12/PCINT5
// D10#     A10     PB6     PWM16       OC1B/0c4B/ADC13/PCINT6
// D11#             PB7     PWM8/16     0C0A/OC1C/#RTS/PCINT7
// D12      A11     PD6                 T1/#OC4D/ADC9
// D13#             PC7     PWM10       CLK0/OC4A
//
// A0       D18     PF7                 ADC7
// A1       D19     PF6                 ADC6
// A2       D20     PF5                 ADC5
// A3       D21     PF4                 ADC4
// A4       D22     PF1                 ADC1
// A5       D23     PF0                 ADC0
//
// New pins D14..D17 to map SPI port to digital pins
//
// MISO     D14     PB3                 MISO,PCINT3
// SCK      D15     PB1                 SCK,PCINT1
// MOSI     D16     PB2                 MOSI,PCINT2
// SS       D17     PB0                 RXLED,SS/PCINT0
//
// Connected LEDs on board for TX and RX
// TXLED    D30     PD5                 XCK1
// RXLED    D17     PB0
// HWB              PE2                 HWB
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

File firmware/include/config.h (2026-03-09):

#pragma once

#define LED_RED LED_BUILTIN_RX
#define LED_GREEN LED_BUILTIN_TX

// SPI Slave Select Pins
#define SUPPLY_CS 2 // PIN19 - D2/SDA
#define RETURN_CS 3 // PIN18 - D3/SCL
#define MCP_CS 4    // PIN25 - D4/A6
#define MCP_INT 7   // PIN1  - D7

// Flow Sensor Pins
#define FLOW_SENSOR_PIN 0 // RX - D0
#define FLOW_TICKS_PER_LITER 4

// Dip switch pin definitions
#define DS_B3 10
#define DS_B2 9
#define DS_B1 8
#define DS_B0 6

#define NODE_ID_BASE 0x10 // Base node ID

#define VARIANT_FULL 0x01           // Default variant
#define VARIANT_SIMULATED_FLOW 0x02 // Simulated flow variant

#define MODEL 0x01            // TFM-100
#define VARIANT VARIANT_FULL  // Default variant
#define FIRMWARE_VERSION 0x01 // Production version 1

#define PT100_FILTER_RC 5000  // 5s
#define PT100_SAMPLE_RATE 100 // 100ms
#define PT100_ALPHA ((float)PT100_SAMPLE_RATE / ((float)PT100_FILTER_RC + PT100_SAMPLE_RATE))

// EEPROM layout
// First byte reserved for diagnostics storage start (logical offset)
//
// Layout (byte offsets, inclusive ranges):
//   0x00           : reserved (logical diagnostics start pointer)
//   0x1A - 0x1F    : POWER region (6 bytes: 2 bytes magic + 4 bytes max_power)
//   0x20 - 0x29    : ENERGY region (10 bytes: 2 bytes magic + 4 bytes energy_total + 4 bytes energy_24h)
//   0x40 - ...     : DIAGNOSTICS region (starts at 0x40; size defined elsewhere)
//
// Offsets:
#define POWER_EEPROM_OFFSET 0x1A
#define ENERGY_EEPROM_OFFSET 0x20
#define DIAGNOSTICS_EEPROM_OFFSET 0x40

// Region sizes (in bytes) — keep in sync with EEPROM data structures:
#define POWER_EEPROM_SIZE   6   // 2 bytes magic + 4 bytes max_power
#define ENERGY_EEPROM_SIZE 10   // 2 bytes magic + 4 bytes energy_total + 4 bytes energy_24h

// Thermal deadband threshold (°C).
// Both getThermalPower and energyFromVolume_kWh use this one-sided lower-bound guard:
// delta_T below this value is treated as zero (idle circuit or sensor offset).
#define DT_DEADBAND 0.05f

#define ENERGY_EEPROM_SAVE_INTERVAL_MS 60000UL // Persist energy to EEPROM at most once per minute

// Compile-time checks to ensure EEPROM regions do not overlap.
static_assert(POWER_EEPROM_OFFSET + POWER_EEPROM_SIZE <= ENERGY_EEPROM_OFFSET,
              "EEPROM layout error: POWER region overlaps ENERGY region");
static_assert(ENERGY_EEPROM_OFFSET + ENERGY_EEPROM_SIZE <= DIAGNOSTICS_EEPROM_OFFSET,
              "EEPROM layout error: ENERGY region overlaps DIAGNOSTICS region");

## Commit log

2025-03-09 feat(bootloader): add flashing guide and wiring diagram for ATmega32U4
2025-03-15 feat(LEDs): add CANopen LED behavior implementation
2025-03-15 feat(main): implement TFM-100 board management with CAN Bus communication
2025-03-15 docs: add ATmega32U4 pin mapping diagram and README
2025-03-15 chore(LEDs): update error handling for PT100 reading in LED behavior
    [main.cpp]
2025-03-15 feat(PT100): implement PT100 sensor class with initialization and measurement handling
2025-03-19 feat(dip_switch): add DIP switch reading functionality to determine node ID
2025-03-19 fix(main): improve hardware failure handling in setup function
    [main.cpp]
2025-03-19 fix(main): change MCP_INT pin configuration to INPUT_PULLUP
    [main.cpp]
2025-03-19 feat(J1939): add J1939_Temperature class for temperature data handling
2025-03-20 fix(dip_switch): invert digital read logic for dip switch pins
2025-03-20 fix(J1939): correct byte order in temperature data serialization
2025-03-20 feat(PT100): add exponential moving average filter for temperature readings
2025-03-20 feat(J1939): add filtered temperature and flow class with data handling
2025-03-20 fix(config): update variant definitions for correct flow and default settings
    [config.h]
2025-03-20 refactor(main): remove commented-out CAN bus handling code
2025-03-20 feat(flow): implement flow sensor handling with interrupt and processing logic
2025-03-20 fix(main): set hardware failure flag and improve handling in setup
    [main.cpp]
2025-03-24 fix(flow): correct delta_tick calculation to use UINT16_MAX for rollover handling
2025-03-25 feat(flow): enhance flow measurement with new calculation method and timeout handling
2025-03-25 fix(J1939): update flow parameter type to uint16_t in J1939_FilteredTemperatureAndFlow class
    [main.cpp]
2025-03-25 fix(flow): replace last_sample_time with last_millis for consistent timing in flow calculations
2025-03-25 fix(flow): correct overflow handling in tick calculation and update constant definitions for consistency
    [main.cpp]
2025-03-25 fix(flow): update node status based on flow rate to manage sleep and run states
    [main.cpp]
2025-03-25 fix(LEDs): update timing mechanism in LEDs to remove glitch in LED driving
    [main.cpp]
2025-03-25 refactor(LEDs): fixed indentation
2025-03-26 fix(LEDs): optimize LED status handling and improve flickering logic
2025-03-28 fix(board): created TFM-100 custom board configuration to solve the issue with led during serial communication
    [pins_arduino.h]
2025-03-31 fix: replace Arduino.h with standard headers for better portability and clarity
2025-03-31 refactor(dip_switch): moved dip switch reading functionality inside main
2025-03-31 fix(flow): expose flow_l_h variable and add isFlowZero function
    [main.cpp]
2025-03-31 refactor(): set pinMode for dip switch pins in dip_switch_read function
2025-08-17 chore: Update firmware/boards/variants/TFM_100/pins_arduino.h
2025-08-17 feat: added EasyEDA project and ger files
    (cherry picked from commit fb153301861f3cb72cb22ce1adafe83306dd2636)
    [Drill_NPTH_Through.DRL, Drill_PTH_Through.DRL, Drill_PTH_Through_Via.DRL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]
2025-08-17 fix(hardware): added routing for flow signal and added pull-up resistors for easy bootloader flash
    [Drill_NPTH_Through.DRL, Drill_PTH_Through.DRL, Drill_PTH_Through_Via.DRL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]
2025-09-22 feat: enhance telemetry and flow handling with new external variables and flow status check
2025-09-22 refactor(led): move to cpp
2025-09-22 refactor(led): simplify LEDs_process function and update error handling
    [main.cpp]
2025-09-22 refactor: moved LEDs under src
2025-09-22 refactor(led): convert LED management to class-based structure and update initialization
2025-09-22 fix(flow): isFlowing returns true when water is flowing
2025-09-22 fix(): manage clientConnectedin drawHardwareFailure, driver properly LEDs
    [LEDs.cpp, cli.cpp, main.cpp]
2025-09-22 feat(cli): allow manual reboot in drawHardwareFailure
    [cli.cpp, main.cpp]
2025-09-23 feat(cli): enhance drawSystemInfoScreen to display PT100 sensor and CAN driver data
2025-09-23 fix(cli): swap diagnostics and system info screen navigation
    [cli.cpp]
2025-09-23 fix(cli): add footer to calibration screen for improved user guidance
    [cli.cpp]
2025-09-24 fix(cli): made MAX31865 sensor public
2025-09-30 refactor(LEDs): enhance LED state machine with detailed documentation and improved pin handling
2025-10-02 fix(J1939): track consumed bytes in J1939Manager for improved pool management
2025-10-02 fix(J1939): remove current_consumed_ tracking from J1939Manager for cleaner state management
2025-10-02 fix(J1939): enforce inter-frame gap between DT frames in processCurrent method
2025-10-08 fix(J1939): refactor payload handling by replacing scratch buffer with frame_payload and adding fillFramePayload helper
2025-10-13 feat(diagnostics): implement DTC management system with error tracking and updates
    [LEDs.cpp, main.cpp]
2025-10-13 feat(cli): enhance diagnostics screen with error reset option and detailed error display
    [cli.cpp]
2025-10-13 refactor(utils): optimize utility functions for string formatting to reduce flash footprint
2025-10-18 refactor(LEDs): remove HwFailure parameter from process method for simplification
2025-12-14 fix(diagnostics): correct DTC index usage in diagnostics entry change handling
    [diag_comm.cpp]
2025-12-15 fix(webui): initialize temperature and energy variables to zero
2026-02-25 fix: Apply suggestions from code review
    [LEDs.cpp, main.cpp]
2026-02-25 feat: implement energy and power management with EEPROM persistence and CLI integration
2026-02-25 fix: removed legacy code
    [main.cpp]
2026-02-25 feat(diag_comm): receive message for energy reset
    [main.cpp]
2026-02-25 feat(diag_comm): Added streaming of energy and power
2026-02-25 fix(cli): fixed refresh logic
    [diag_comm.cpp]
2026-02-25 fix(can_messages): correct CAN payload encoding comment for PowerAndEnergy (#12)
    * Initial plan
    * fix(can_messages): correct encoding comment to little-endian with accurate LSB units
    ---------
2026-02-25 release(v1): firmware production readiness — version bump, memory safety, dead code removal (#14)
    * feat(config): update FIRMWARE_VERSION to 0x01 for production v1
    Change FIRMWARE_VERSION from 0xFF (test placeholder) to 0x01
    to indicate production firmware version 1. This also removes the
    '#warning FIRMWARE_VERSION is 0xFF' compile-time warning.
    * fix(diag_comm): report actual power percent instead of hardcoded 0
    The P% serial parameter was hardcoded to 0.0f instead of reporting
    the real power percentage from the Power object. Add Power extern to
    diag_comm.h and use powerObj.getPowerPercent() in periodically_update().
    Also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
    [LEDs.cpp, config.h, diag_comm.cpp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]
2026-03-03 docs(bootloader): migrate to USBasp, add 10-pin pinout, split fuse/flash commands, drop avrdude.conf (#15)
    * Improve ATMega reflash documentation: USBasp, split commands, remove avrdude.conf
    * docs(bootloader): replace ArduinoISP image with USBasp 10-pin pinout and adapter info
    * fix: improve descriptions and resized image
    * docs(bootloader): fix inaccurate fuse bit explanations for hfuse and efuse
    * fix: update BODLEVEL threshold in fuse settings to 2.6 V
2026-03-06 fix(energy): defer EEPROM persist to interval-based call to reduce write wear
    (cherry picked from commit df448ee9359091d8163efb94ff4b3119701250c9)
    [config.h, main.cpp]
2026-03-06 fix(can): clear canRxPending before draining RX buffer to avoid lost interrupts
    (cherry picked from commit 3f254ad2943429e64d03706cc1beaf0763fb42e8)
    [main.cpp]
2026-03-06 fix(webui): update prop naming conventions for consistency
2026-03-06 fix: Fix casing of power-kW prop in TelemetryCard
2026-03-09 Fix negative energy accumulation caused by temperature anomaly at idle (#27)
    [config.h]
2026-03-09 fix(flow): replace TCNT1 timer with millis(), add EMA LPF, fix state machine (#25)
2026-03-10 fix(flow): eliminate startup spike and 30-second periodic false-flow artifacts (#29)

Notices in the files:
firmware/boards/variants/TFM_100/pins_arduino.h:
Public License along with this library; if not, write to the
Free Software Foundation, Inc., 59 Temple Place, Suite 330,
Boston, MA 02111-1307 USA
